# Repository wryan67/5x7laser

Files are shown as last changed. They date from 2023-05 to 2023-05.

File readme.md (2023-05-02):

## 5x7 laser gun

This lasergun can be produced using 5" x 7" sheets of plastic or basswood.  

<a target=_blank href="https://raw.githubusercontent.com/wryan67/5x7laser/main/photos/0171c5aad9a224693b09b8947d892903f43abc70b3.jpg">
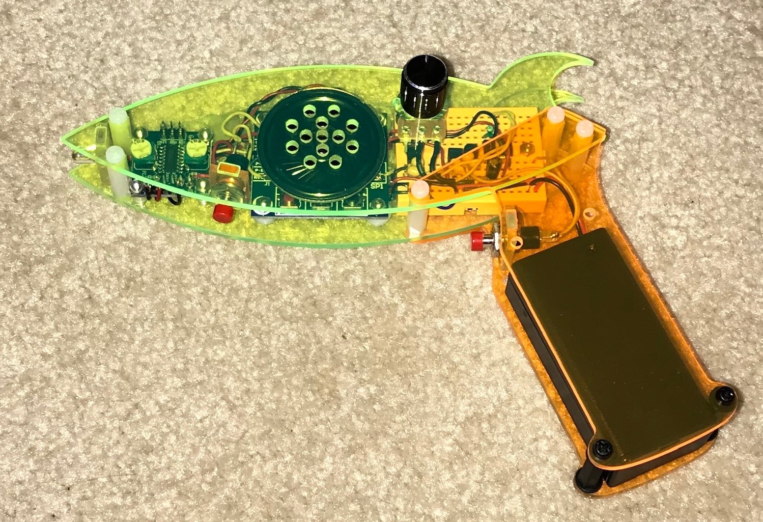
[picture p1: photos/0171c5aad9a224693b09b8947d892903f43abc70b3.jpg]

</a>

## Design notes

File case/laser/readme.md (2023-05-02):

** -----------------------
** For the case and handle, 
** use the System point of 
**      reference!
***  (Use Input CSYS)

If case is solid:
  1. plot-case1.dxf    -   5%  *
  2. plot-case2.dxf    -  35%  *

If case is transparent:
  1. plot-case1m.dxf   -   5%  *
  2. plot-case2m.dxf   -  35%  *

Front only (solid):
  1. plot-case1f.dxf   -   5%  *
  2. plot-case2f.dxf   -  35%  *

If solid handle:
  1. plot-handle1.dxf  -   5%
  2. plot-handle2.dxf  -  35%

If transparent handle:
  1. plot-handle1m.dx  -   5%
  2. plot-handle2m.dx  -  35%

All spacers:
  1.  plot-spacers.dxf  - 35%

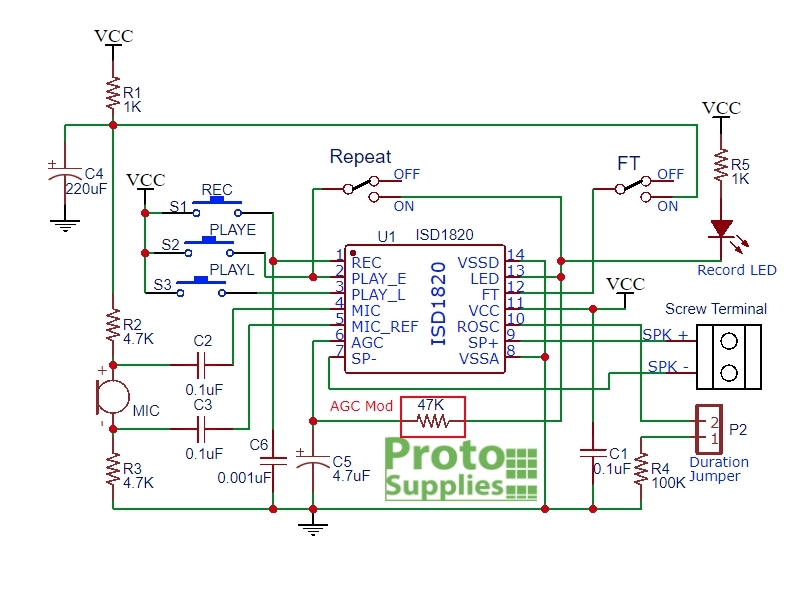
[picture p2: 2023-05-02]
schematic/datasheets/ISD1820-Schematic.jpg

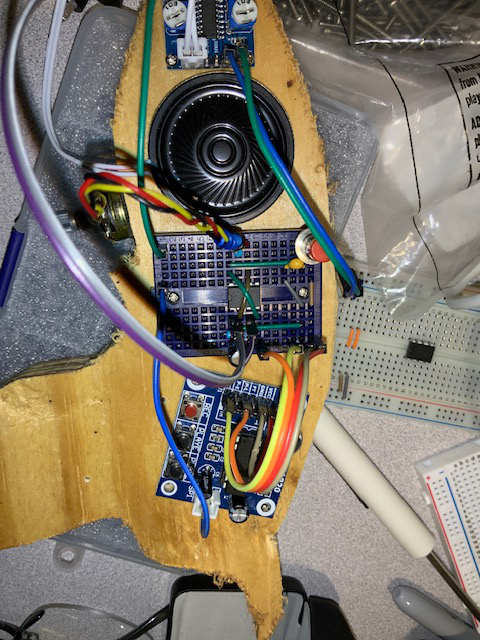
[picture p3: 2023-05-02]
photos/0EB626F5-53C3-48A2-8D61-16B651253186-2090-000001E3B6790D59.JPG

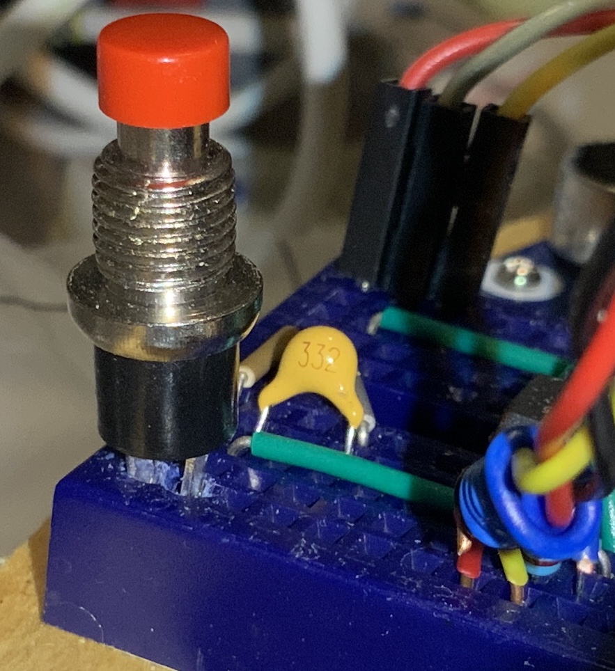
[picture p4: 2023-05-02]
photos/81DD8B38-144E-4452-A4E2-50B8B52A12D1-2090-000001E81675E1E7.jpg

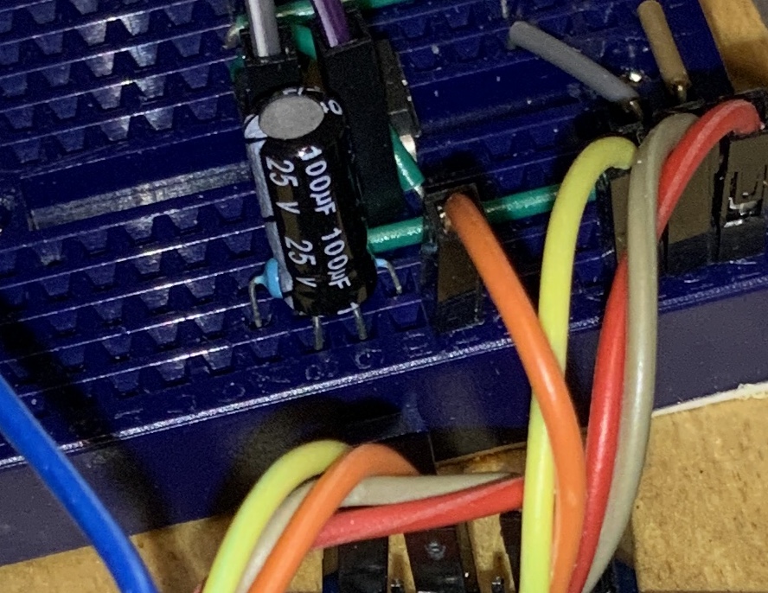
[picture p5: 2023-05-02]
photos/343F5F6C-72F8-4F98-A707-56C6934FBF5B-2090-000001E46D74EF79.jpg

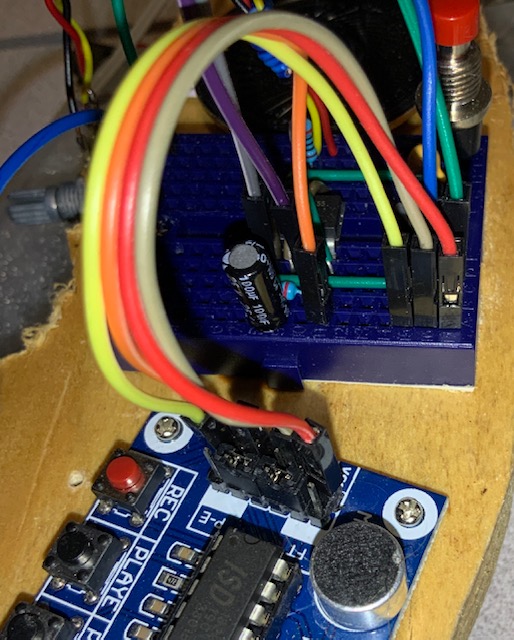
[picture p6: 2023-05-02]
photos/767D7ABD-2B31-472F-8BD6-DF1199BEE2B4-2090-000001E356E05ED7.jpg

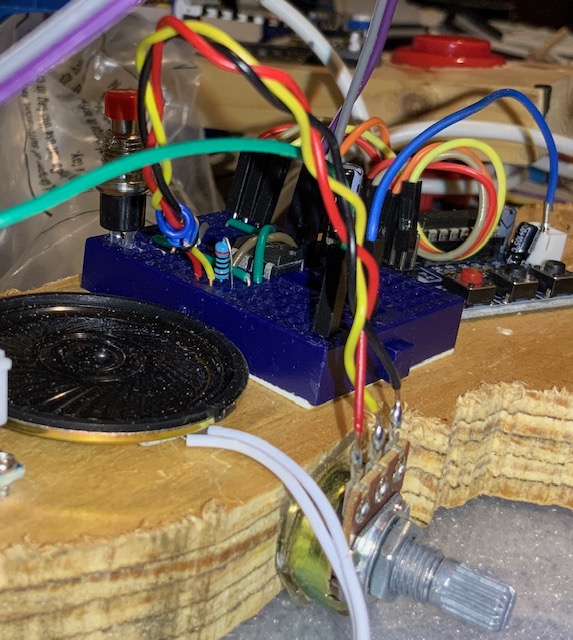
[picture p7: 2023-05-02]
photos/74F2E2E8-B6AC-48FE-9EBC-FF982D334DC6-2090-000001E53F1EEB27.jpg

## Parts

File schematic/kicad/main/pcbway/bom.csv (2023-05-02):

Id | Designator | Footprint | Quantity | Designation | Supplier and ref
1 | REC1 | LED_0805_2012Metric | 1 | Red
2 | J10,J16,J12,J9,J15,J11,J14,J13 | PinHeader_1x02_P2.54mm_Vertical_Wide | 8 | LED
3 | R8,R11 | R_0805_2012Metric | 2 | 10k
4 | C13 | C_0805_2012Metric | 1 | 106
5 | R17,R15,R18,R16 | R_0805_2012Metric | 4 | 200 Ω
6 | J4 | PinHeader_1x02_P2.54mm_Vertical_Wide | 1 | Mic
7 | PWR1,PWR2 | LED_0805_2012Metric | 2 | Green
8 | IC1 | LM4871 | 1 | LM4871MX_NOPB
9 | J1 | PinHeader_1x02_P2.54mm_Vertical_Wide | 1 | Power
10 | C3 | CP_Radial_Tantal_D6.0mm_P2.50mm | 1 | 220 µF
11 | U3 | SOIC-8_3.9x4.9mm_P1.27mm | 1 | NE555D
12 | J2 | PinHeader_1x02_P2.54mm_Vertical_Wide | 1 | Rec
13 | R14,R7,R13 | R_0805_2012Metric | 3 | 100k
14 | J3 | PinHeader_1x02_P2.54mm_Vertical_Wide | 1 | Play
15 | PLAY6,PLAY4,PLAY5,PLAY3 | LED_0805_2012Metric | 4 | Yellow
16 | U2 | ISD1820 | 1 | ISD1820
17 | PLAY1,PLAY2 | LED_0805_2012Metric | 2 | Blue
18 | R12,R19,R9,R4,R1,R6,R10 | R_0805_2012Metric | 7 | 1k
19 | J6 | PinHeader_1x02_P2.54mm_Vertical_Wide | 1 | Speaker
20 | U1 | ua7805-KTT-_R-PSFM-G3_ | 1 | ua7805
21 | J7,J8 | PinHeader_1x02_P2.54mm_Vertical_Wide | 2 | 100k pot
22 | Q3 | SOT-23 | 1 | PMBT2222A
23 | C9,C2,C5,C4 | C_0805_2012Metric | 4 | 104
24 | Q2,Q1 | SOT-23 | 2 | 2PB709AXL
25 | R2,R3 | R_0805_2012Metric | 2 | 4.7k
26 | C1 | C_0805_2012Metric | 1 | 334
27 | C12,C11 | C_0805_2012Metric | 2 | 105
28 | C7,C6,C14 | C_0805_2012Metric | 3 | 102
29 | C8 | C_0805_2012Metric | 1 | 475
30 | C10 | C_0805_2012Metric | 1 | 394
31 | R5 | R_0805_2012Metric | 1 | 80k

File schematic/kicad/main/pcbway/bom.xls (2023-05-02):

Id | Designator | Description/Footprint | Quantity | Value | watt | min voltage | SMD | SMD | THD
1 | R19,R12,R9,R4,R1,R6,R10 | R_0805_2012Metric | 7 | 1k | 1/8w |  | Y | 7 | 0
2 | PLAY2,PLAY1 | LED_0805_2012Metric | 2 | Blue |  |  | Y | 2 | 0
3 | U3 | SOIC-8_3.9x4.9mm_P1.27mm | 1 | NE555D |  |  | Y | 1 | 0
4 | C14,C7,C6 | C_0805_2012Metric | 3 | 102 |  | 10v | Y | 3 | 0
5 | REC1 | LED_0805_2012Metric | 1 | Red |  |  | Y | 1 | 0
6 | J10,J16,J12,J9,J15,J11,J14,J13 | Header_1x02_P2.54mm | 8 | Female_Round_Machine_Pin |  |  | N | 0 | 8
7 | R8,R11 | R_0805_2012Metric | 2 | 10k | 1/8w |  | Y | 2 | 0
8 | C13 | C_0805_2012Metric | 1 | 106 |  | 10v | Y | 1 | 0
9 | R17,R15,R18,R16 | R_0805_2012Metric | 4 | 200 ? | 1/8w |  | Y | 4 | 0
10 | J4 | Header_1x02_P2.54mm | 1 | Female_Round_Machine_Pin |  |  | N | 0 | 1
11 | PWR1,PWR2 | LED_0805_2012Metric | 2 | Green |  |  | Y | 2 | 0
12 | IC1 | SOIC-8_3.9x4.9mm_P1.27mm | 1 | LM4871MX_NOPB |  |  | Y | 1 | 0
13 | J1 | Header_1x02_P2.54mm | 1 | Female_Round_Machine_Pin |  |  | N | 0 | 1
14 | C3 | C_Electrolytic_D6.0mm_P2.50mm_H7mm | 1 | 220 µF |  | ? | N | 0 | 1
15 | J2 | Header_1x02_P2.54mm | 1 | Female_Round_Machine_Pin |  |  | N | 0 | 1
16 | R14,R7,R13 | R_0805_2012Metric | 3 | 100k | 1/8w |  | Y | 3 | 0
17 | J3 | Header_1x02_P2.54mm | 1 | Female_Round_Machine_Pin |  |  | N | 0 | 1
18 | PLAY6,PLAY4,PLAY5,PLAY3 | LED_0805_2012Metric | 4 | Yellow |  |  | Y | 4 | 0
19 | U2 | DIP-14 | 1 | ISD1820 |  |  | N | 0 | 1
20 | J6 | Header_1x02_P2.54mm | 1 | Female_Round_Machine_Pin |  |  | N | 0 | 1
21 | U1 | TO-263 | 1 | UA7805CKTTR |  |  | Y | 1 | 0
22 | J7,J8 | Header_1x02_P2.54mm | 2 | Female_Round_Machine_Pin |  |  | N | 0 | 2
23 | Q3 | SOT-23 | 1 | PMBT2222A |  |  | Y | 1 | 0
24 | C9,C2,C5,C4 | C_0805_2012Metric | 4 | 104 |  | 10v | Y | 4 | 0
25 | Q2,Q1 | SOT-23 | 2 | 2PB709AXL |  |  | Y | 2 | 0
26 | R2,R3 | R_0805_2012Metric | 2 | 4.7k | 1/8w |  | Y | 2 | 0
27 | C1 | C_0805_2012Metric | 1 | 334 |  | 10v | Y | 1 | 0
28 | C12,C11 | C_0805_2012Metric | 2 | 105 |  | 10v | Y | 2 | 0
29 | C8 | C_0805_2012Metric | 1 | 475 |  | 10v | Y | 1 | 0
30 | C10 | C_0805_2012Metric | 1 | 394 |  | 10v | Y | 1 | 0
31 | R5 | R_0805_2012Metric | 1 | 80.6k | 1/8w |  | Y | 1 | 0
 | Totals |  | 64 |  |  |  |  | 47 | 17

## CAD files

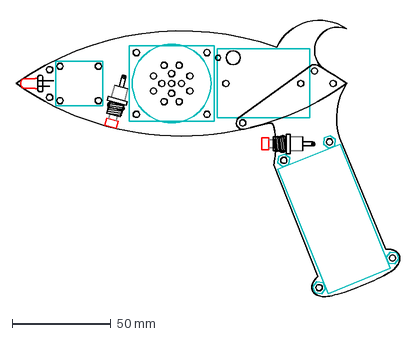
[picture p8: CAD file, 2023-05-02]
case/cnc/lasergun6.dxf
194.8 x 142.3 mm

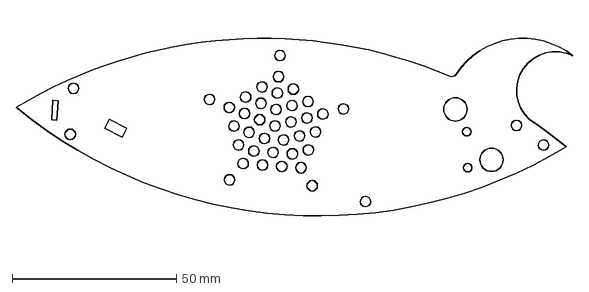
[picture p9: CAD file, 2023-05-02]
case/laser/plot-case2f.dxf
169.3 x 71.6 mm

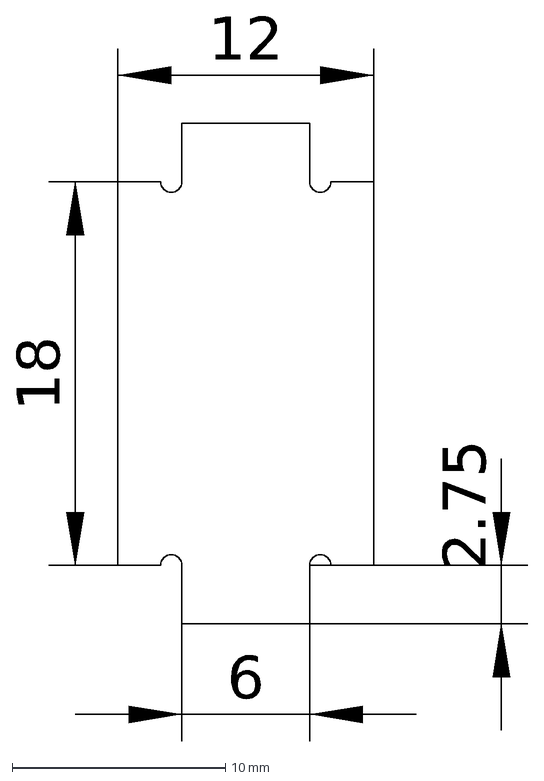
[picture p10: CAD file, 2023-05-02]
case/laser/save/plot-barrel.dxf
12
18
6
2.75

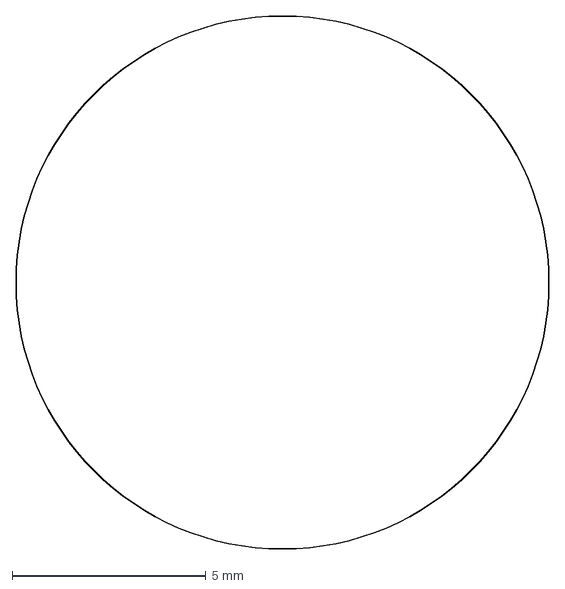
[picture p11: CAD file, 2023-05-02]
knob/knob.dxf
13.8 x 13.8 mm

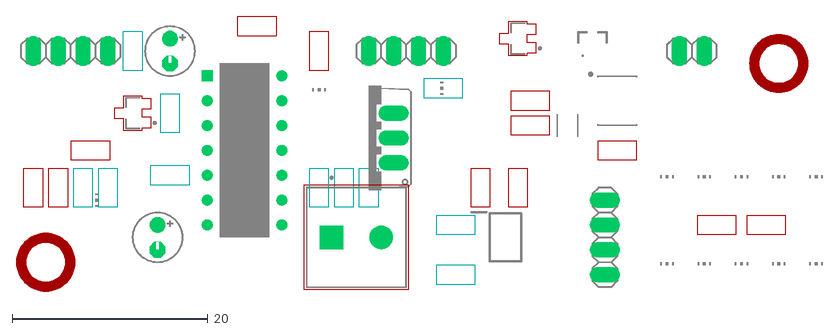
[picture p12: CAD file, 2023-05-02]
schematic/eagle/laser-min.dxf
82.4 x 28.1

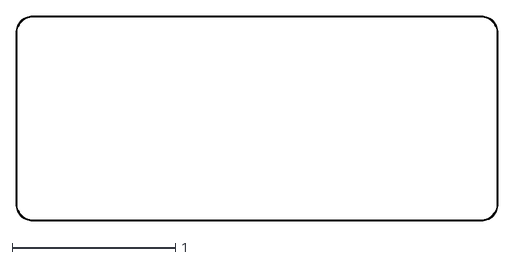
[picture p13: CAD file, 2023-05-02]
schematic/kicad/main/gerber/laser-Edge_Cuts.dxf
2.95 x 1.25

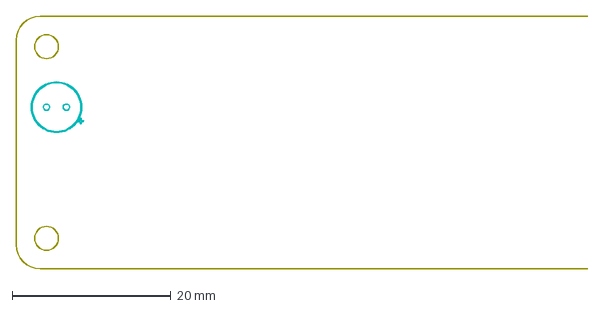
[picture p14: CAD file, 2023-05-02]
schematic/kicad/main/laser-Edge_Cuts.dxf
71.9 x 31.8 mm

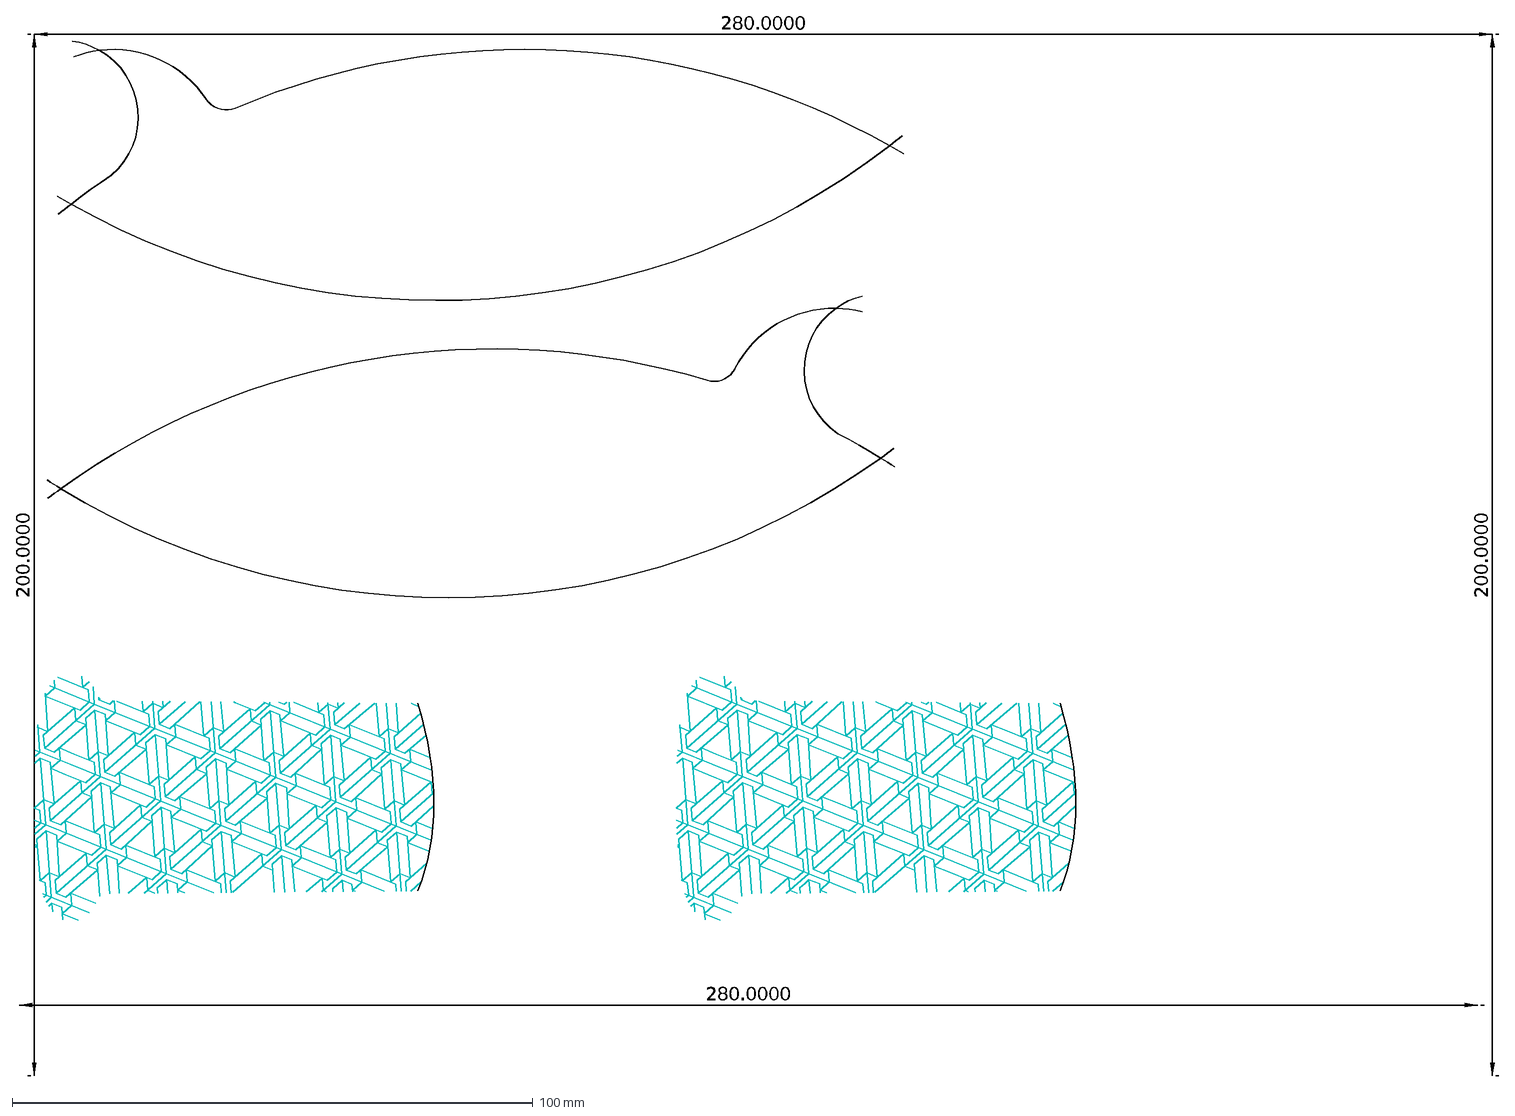
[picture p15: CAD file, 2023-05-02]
case/laser/save/plot1.dxf
200.0000
280.0000

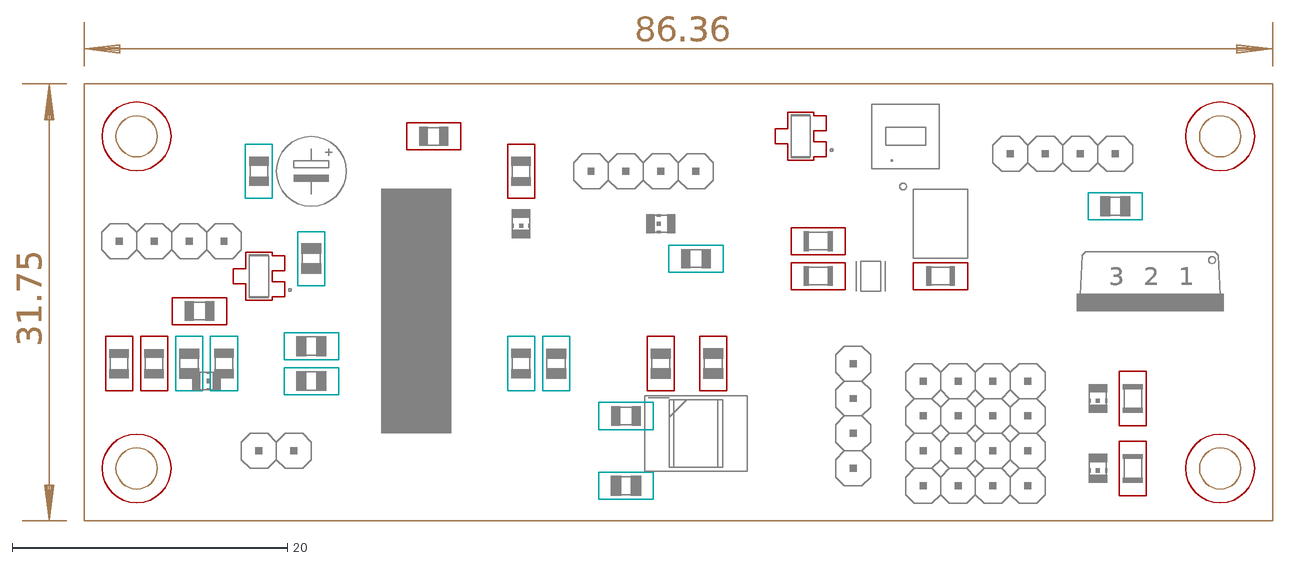
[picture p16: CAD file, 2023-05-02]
schematic/eagle/laser.dxf
31.75
86.36
1
2
3

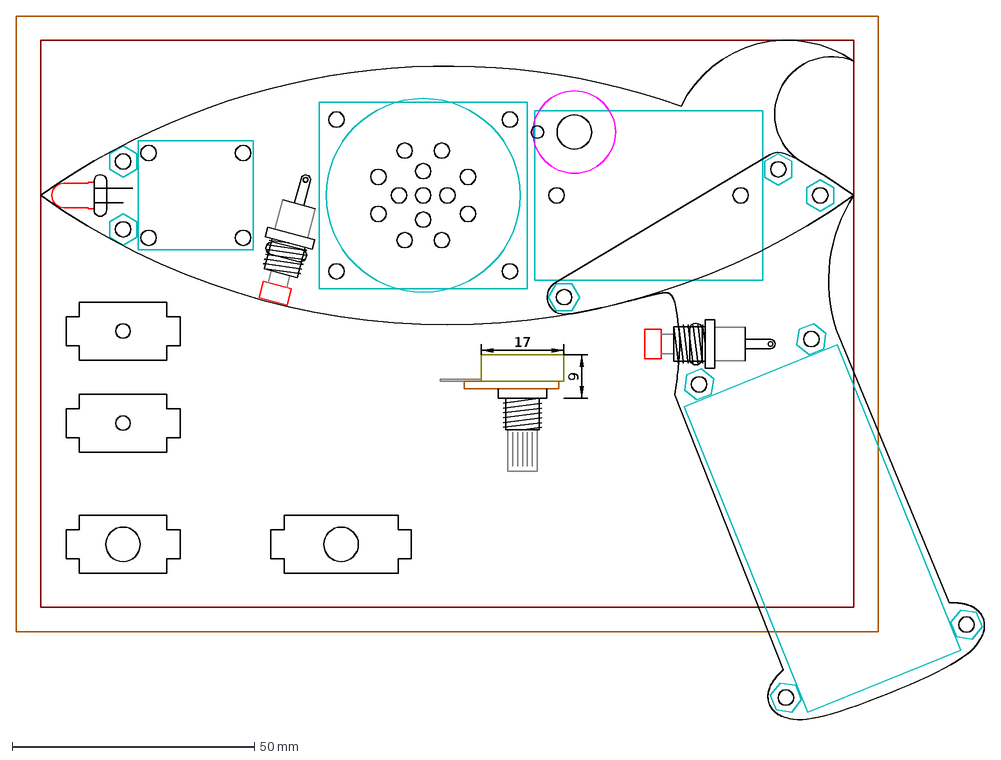
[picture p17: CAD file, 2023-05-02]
case/cnc/lasergun7.dxf
9
17

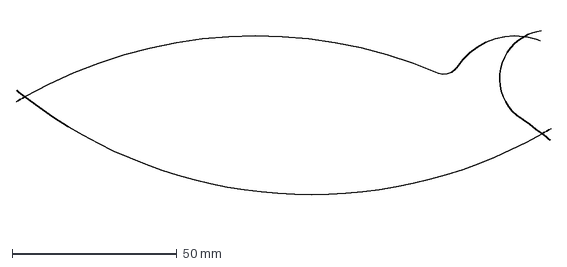
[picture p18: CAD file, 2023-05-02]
case/laser/plot-case1f.dxf
162.6 x 64.0 mm

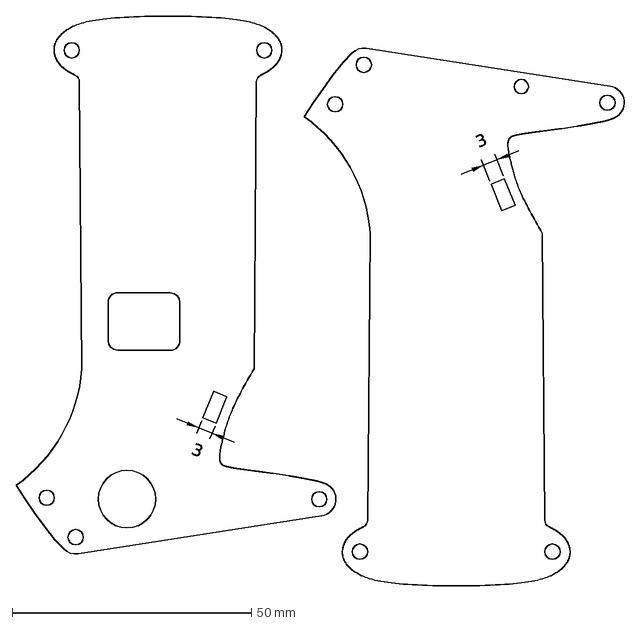
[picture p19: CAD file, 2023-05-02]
case/laser/save/plot-handle2m-bilbo.dxf
3

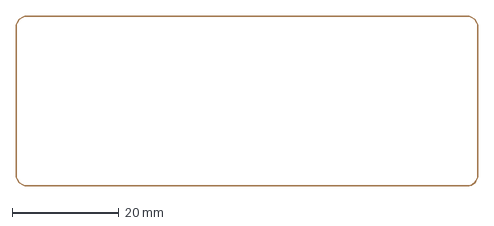
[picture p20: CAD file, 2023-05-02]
schematic/eagle/laser.border.dxf
86.4 x 31.8 mm

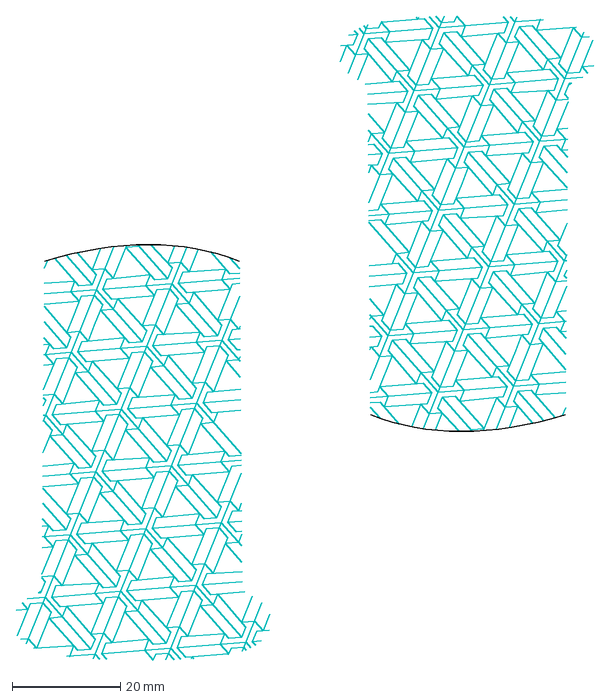
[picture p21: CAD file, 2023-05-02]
case/laser/plot-handle1.dxf
106.6 x 118.9 mm

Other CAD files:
case/laser/lasergun8.dxf
case/cnc/plot-barrel.dxf
case/laser/save/plot-handle.dxf
archive/lasergun.dxf
archive/lasergun2.dxf
archive/lasergun3.dxf
archive/lasergun4.dxf
archive/lasergun5.dxf
archive/plot-body.dxf
archive/plot-handle.dxf
archive/plot-spacers.dxf
archive/plot1.dxf
archive/slot.dxf
archive/test-handle.dxf
archive/test-handle2.dxf
case/cnc/20mm spacer.dxf
case/cnc/lasergun8.dxf
case/cnc/plot-handle-back.dxf
case/cnc/plot-handle.dxf
case/cnc/plot-spacers.dxf
case/cnc/spacers.dxf
case/laser/lasergun10.dxf
case/laser/lasergun11.dxf
case/laser/plot-case1.dxf
case/laser/plot-case1m.dxf
case/laser/plot-case2.dxf
case/laser/plot-case2m.dxf
case/laser/plot-handle.dxf
case/laser/plot-handle1m.dxf
case/laser/plot-handle2.dxf
case/laser/plot-handle2m.dxf
case/laser/plot-spacers.dxf
case/laser/save/20mm spacer.dxf
case/laser/save/controller-pcb.dxf
case/laser/save/plot-case1.dxf
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

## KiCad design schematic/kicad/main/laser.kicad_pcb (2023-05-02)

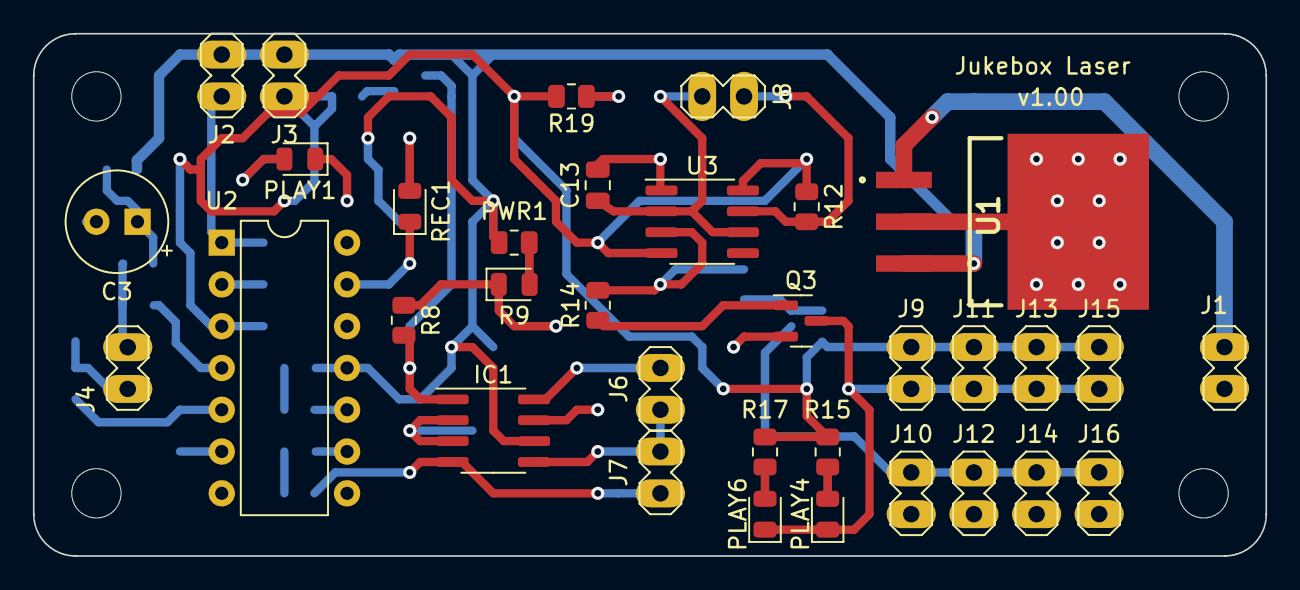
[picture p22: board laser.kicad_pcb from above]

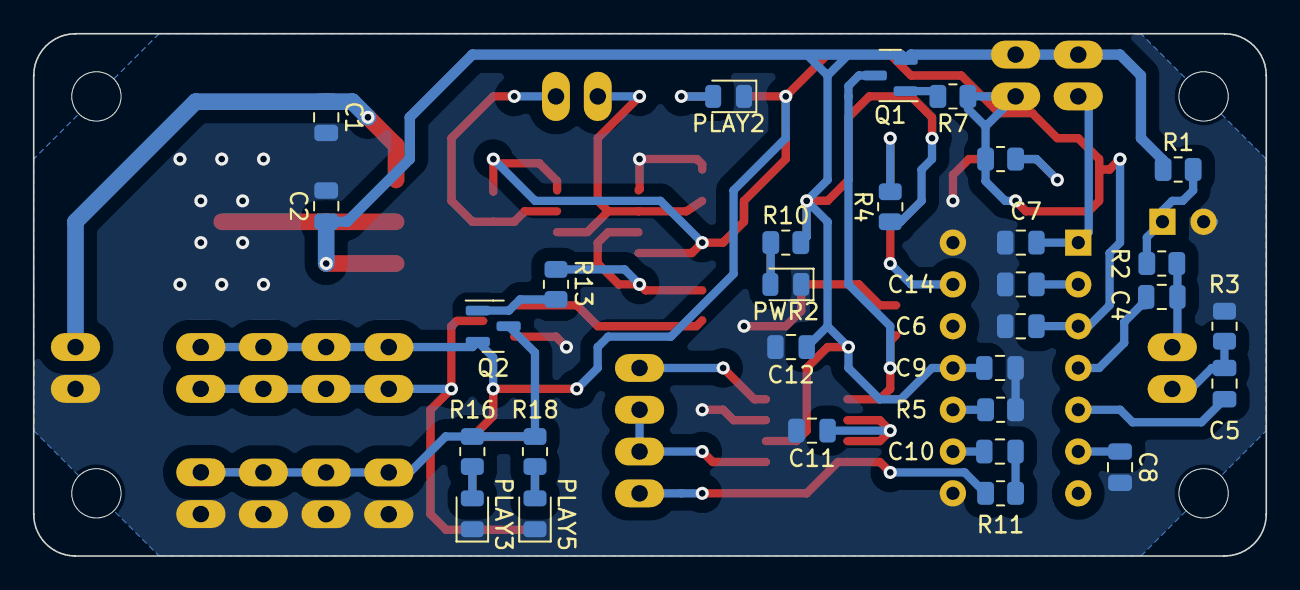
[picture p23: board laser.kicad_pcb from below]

Board: 2 copper layers, 74.9 x 31.8 mm, 64 parts (30 on the bottom side), 38 nets.

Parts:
C1: 334; C_0805_2012Metric
C2, C4, C5, C9: 104; C_0805_2012Metric
C3: 220 µF; CP_Radial_Tantal_D6.0mm_P2.50mm
C6, C7, C14: 102; C_0805_2012Metric
C8: 475; C_0805_2012Metric
C10: 394; C_0805_2012Metric
C11, C12: 105; C_0805_2012Metric
C13: 106; C_0805_2012Metric
IC1: LM4871MX_NOPB; LM4871
J1: Power; PinHeader_1x02_P2.54mm_Vertical_Wide
J2: Rec; PinHeader_1x02_P2.54mm_Vertical_Wide
J3: Play; PinHeader_1x02_P2.54mm_Vertical_Wide
J4: Mic; PinHeader_1x02_P2.54mm_Vertical_Wide
J6: Speaker; PinHeader_1x02_P2.54mm_Vertical_Wide
J7, J8: 100k pot; PinHeader_1x02_P2.54mm_Vertical_Wide
J9, J10, J11, J12, J13, J14, J15, J16: LED; PinHeader_1x02_P2.54mm_Vertical_Wide
PLAY1, PLAY2: Blue; LED_0805_2012Metric
PLAY3, PLAY4, PLAY5, PLAY6: Yellow; LED_0805_2012Metric
PWR1, PWR2: Green; LED_0805_2012Metric
Q1, Q2: 2PB709AXL; SOT-23
Q3: PMBT2222A; SOT-23
R1, R4, R6, R9, R10, R12, R19: 1k; R_0805_2012Metric
R2, R3: 4.7k; R_0805_2012Metric
R5: 80k; R_0805_2012Metric
R7, R13, R14: 100k; R_0805_2012Metric
R8, R11: 10k; R_0805_2012Metric
R15, R16, R17, R18: 200 Ω; R_0805_2012Metric
REC1: Red; LED_0805_2012Metric
U1: ua7805; ua7805-KTT-_R-PSFM-G3_
U2: ISD1820
U3: NE555D; SOIC-8_3.9x4.9mm_P1.27mm

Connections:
+5v: C2.1, C9.1, C12.1, IC1.6 (VDD), J2.2, J3.2, Q1.2 (E), R1.1, R4.1, R9.2, R10.2, U1.3 (OUTPUT), U2.11 (Vcc)
+9v: C1.1, J1.2, U1.1 (INPUT)
/Amplifier/SPK+: IC1.5 (VO1), J6.2, J7.1
/Amplifier/SPK-: IC1.8 (VO2), J6.1
/Jukebox/AGC: C8.1, U2.6 (AGC)
/Jukebox/M+: C4.1, U2.4 (MIC(+))
/Jukebox/M-: C5.1, U2.5 (MIC(-))
/Jukebox/PLAY_E: C14.1, U2.2 (PLAY_E)
Flasher Speed: J8.1, R12.2, U3.7 (DIS)
GND: C1.2, C2.2, C3.2, C6.2, C7.2, C8.2, C9.2, C11.2, C12.2, C13.2, C14.2, IC1.7 (GND), J1.1, J10.2, J12.2, J14.2, J16.2, PLAY1.1 (K), PLAY2.1 (K), PLAY3.1 (K), PLAY5.1 (K), PWR1.1 (K), PWR2.1 (K), Q3.2 (E), R3.2, R5.2, R8.1, U1.2 (COMMON_1), U1.4 (COMMON_2), U2.8 (VSSA), U2.14 (VSSD), U3.1 (GND)
Mic(+): C4.2, J4.2, R2.2
Mic(-): C5.2, J4.1, R3.1
unnamed: C3.1, R1.2, R2.1
unnamed: C10.2, R11.2
unnamed: C11.1, IC1.2 (BYPASS), IC1.3 (+IN)
unnamed: C13.1, J8.2, U3.2 (TR), U3.6 (THR)
unnamed: J10.1, J12.1, J14.1, J16.1, Q2.3 (C), R16.2, R18.2
unnamed: J9.2, J11.2, J13.2, J15.2, PLAY4.1 (K), PLAY6.1 (K), Q3.3 (C)
unnamed: PLAY1.2 (A), R6.1
unnamed: PLAY2.2 (A), R19.1
unnamed: PLAY3.2 (A), R16.1
unnamed: PLAY4.2 (A), R15.1
unnamed: PLAY5.2 (A), R18.1
unnamed: PLAY6.2 (A), R17.1
unnamed: PWR1.2 (A), R9.1
unnamed: PWR2.2 (A), R10.1
unnamed: Q1.1 (B), R7.2
unnamed: Q2.1 (B), R13.2
unnamed: Q3.1 (B), R14.1
unnamed: R4.2, REC1.2 (A)
unnamed: REC1.1 (K), U2.13 (RECLED)
unnamed: R5.1, U2.10 (ROSC)
unnamed: R13.1, R14.2, U3.3 (Q)
PLAY: C6.1, J3.1, J9.1, J11.1, J13.1, J15.1, Q2.2 (E), R6.2, R7.1, R12.1, R15.2, R17.2, R19.2, U2.3 (PLAY_L), U3.4 (R), U3.8 (VCC)
REC: C7.1, J2.1, U2.1 (REC)
SPK(+): C10.1, U2.9 (SPK(+))
Shutdown: IC1.1 (SHUTDOWN), Q1.3 (C), R8.2
VOL(-): IC1.4 (-IN), J7.2, R11.1

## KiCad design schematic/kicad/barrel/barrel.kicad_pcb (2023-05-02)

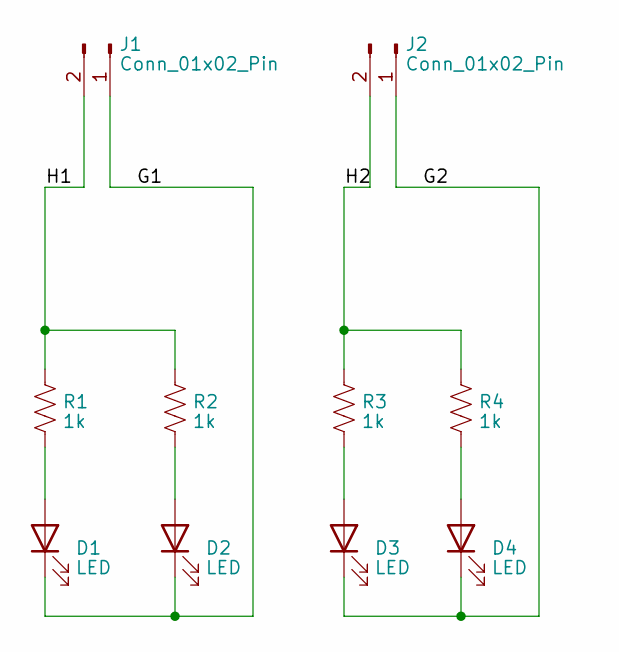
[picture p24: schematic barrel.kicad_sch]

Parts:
D1, D2, D3, D4: LED; LED_0805_2012Metric
J1, J2: Conn_01x02_Pin; PinHeader_1x02_P2.54mm_Vertical_Wide
R1, R2, R3, R4: 1k; R_0805_2012Metric

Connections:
/G1: D1.1 (K), D2.1 (K), J1.1
/G2: D3.1 (K), D4.1 (K), J2.1
/H1: J1.2, R1.1, R2.1
/H2: J2.2, R3.1, R4.1
unnamed: D1.2 (A), R1.2
unnamed: D2.2 (A), R2.2
unnamed: D3.2 (A), R3.2
unnamed: D4.2 (A), R4.2

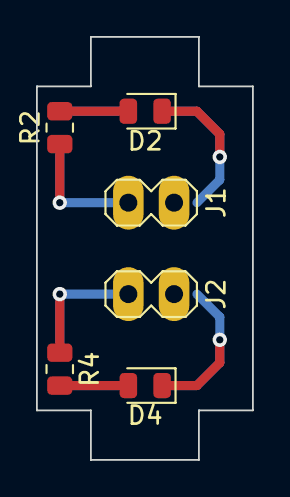
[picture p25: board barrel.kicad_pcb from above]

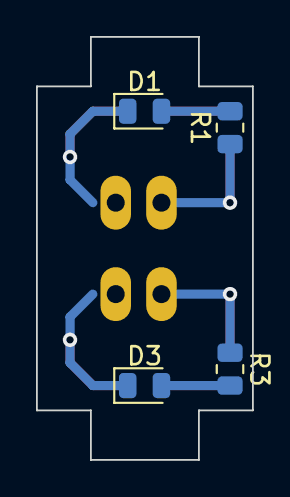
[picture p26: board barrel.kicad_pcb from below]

Board: 2 copper layers, 12.0 x 23.5 mm, 10 parts (4 on the bottom side), 8 nets.

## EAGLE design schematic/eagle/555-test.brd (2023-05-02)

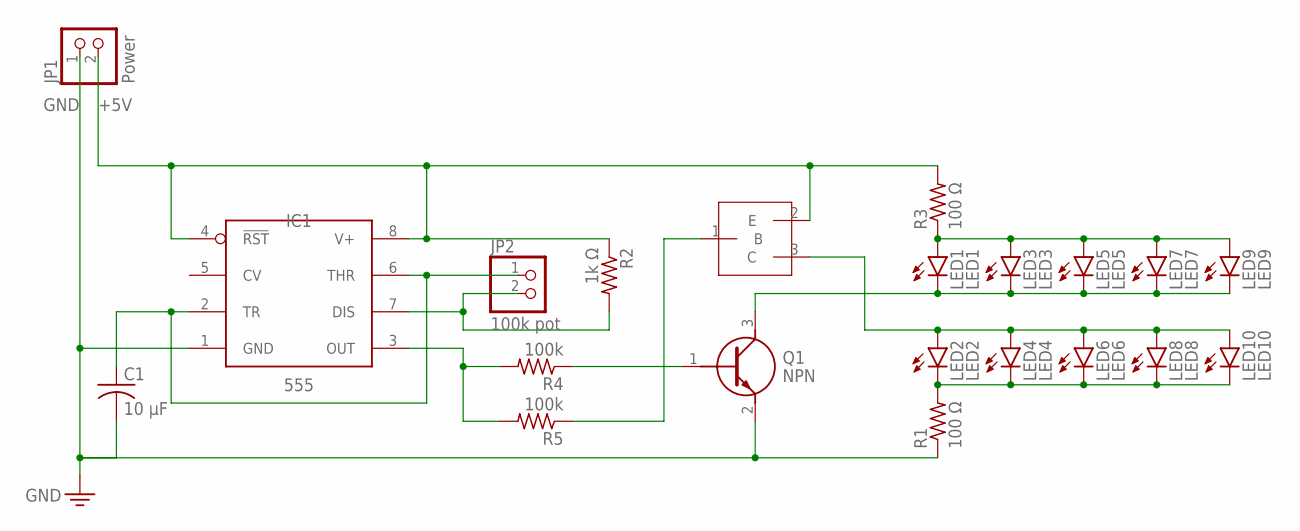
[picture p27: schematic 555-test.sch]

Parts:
C1: 10 μF; CAPC2012X110
IC1: 555; SOIC127P599X175-8N
JP1: Power; 1X02
JP2: 100k pot; 1X02
LED1: LED1; CHIP-LED0805
LED2: LED2; CHIP-LED0805
LED3: LED3; CHIP-LED0805
LED4: LED4; CHIP-LED0805
LED5: LED5; CHIP-LED0805
LED6: LED6; CHIP-LED0805
LED7: LED7; CHIP-LED0805
LED8: LED8; CHIP-LED0805
LED9: LED9; CHIP-LED0805
LED10: LED10; CHIP-LED0805
Q1: NPN; PMBT2222A215
R1, R3: 100 Ω; M0805
R2: 1k Ω; M0805
R4, R5: 100k; M0805
U$1: PNP; SOT95P230X110-3N

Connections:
+5V: IC1.4 (!RST), IC1.8 (V+), JP1.2, R2.1, R3.2, U$1.2 (E)
GND: C1.2, IC1.1 (GND), JP1.1, Q1.2 (E), R1.1
unnamed: C1.1, IC1.2 (TR), IC1.6 (THR), JP2.1
unnamed: IC1.3 (OUT), R4.2, R5.2
unnamed: Q1.1 (B), R4.1
unnamed: LED2.C, LED4.C, LED6.C, LED8.C, LED10.C, R1.2
unnamed: IC1.7 (DIS), JP2.2, R2.2
unnamed: LED1.A, LED3.A, LED5.A, LED7.A, LED9.A, R3.1
unnamed: LED1.C, LED3.C, LED5.C, LED7.C, LED9.C, Q1.3 (C)
unnamed: R5.1, U$1.1 (B)
unnamed: LED2.A, LED4.A, LED6.A, LED8.A, LED10.A, U$1.3 (C)

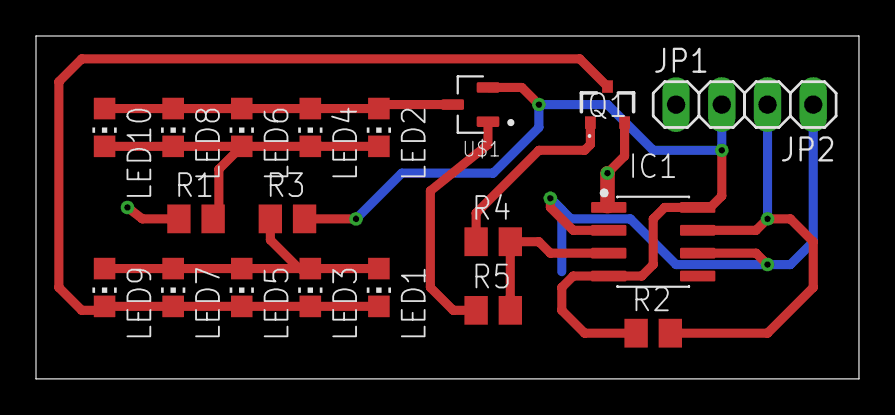
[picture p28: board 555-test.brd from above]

Board: 2 copper layers, 45.7 x 19.1 mm, 21 parts (1 on the bottom side), 11 nets.

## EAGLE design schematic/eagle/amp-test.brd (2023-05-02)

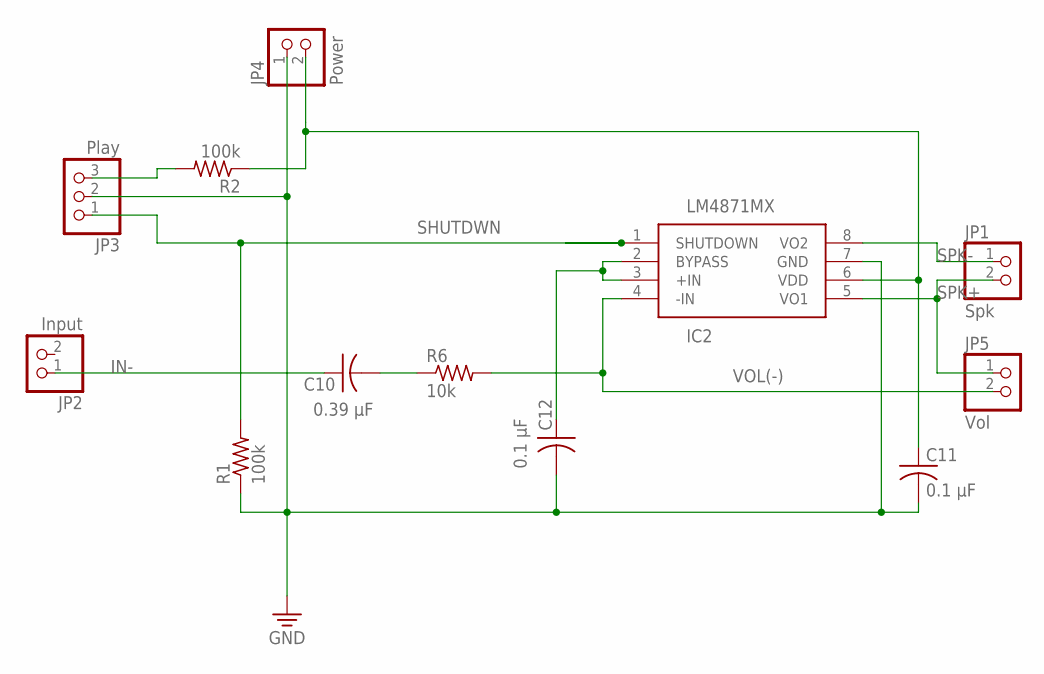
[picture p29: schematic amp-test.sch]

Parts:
C10: 0.39 μF; C0805
C11, C12: 0.1 μF; C0805
IC2: LM4871MX; SOIC127P600X175-8N
JP1: Spk; 1X02
JP2: Input; 1X02
JP3: Play; 1X03
JP4: Power; 1X02
JP5: Vol; 1X02
R1, R2: 100k; R0805
R6: 10k; R0805

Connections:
+5V: C11.1, IC2.6 (VDD), JP4.2, R2.1
GND: C11.2, C12.2, IC2.7 (GND), JP3.2, JP4.1, R1.1
IN-: C10.1, JP2.1
unnamed: JP3.3, R2.2
unnamed: C10.2, R6.1
unnamed: C12.1, IC2.2 (BYPASS), IC2.3 (+IN)
SHUTDWN: IC2.1 (SHUTDOWN), JP3.1, R1.2
SPK+: IC2.5 (VO1), JP1.2, JP5.1
SPK-: IC2.8 (VO2), JP1.1
VOL(-): IC2.4 (-IN), JP5.2, R6.2

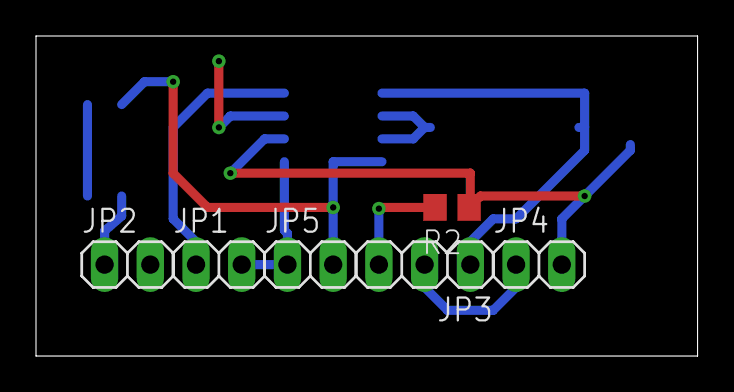
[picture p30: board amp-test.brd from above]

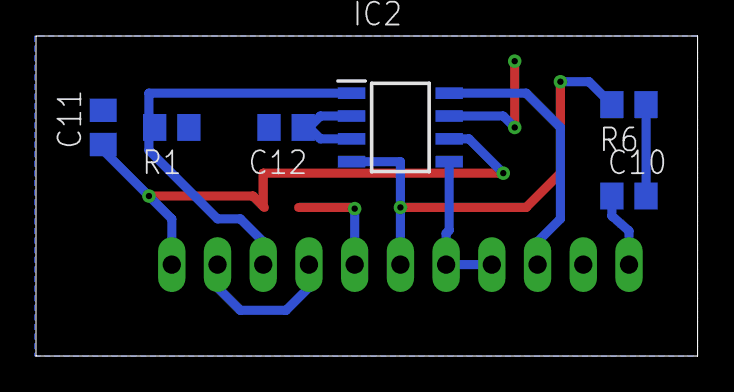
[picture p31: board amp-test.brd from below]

Board: 2 copper layers, 36.8 x 17.8 mm, 12 parts (6 on the bottom side), 10 nets.

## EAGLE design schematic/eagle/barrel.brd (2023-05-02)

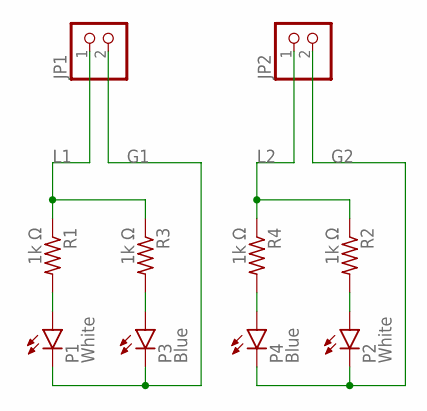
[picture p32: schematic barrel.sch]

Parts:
JP1, JP2: PINHD-1X2; 1X02
P1, P2: White; CHIP-LED0805
P3, P4: Blue; CHIP-LED0805
R1, R2, R3, R4: 1k Ω; M0805

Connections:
G1: JP1.2, P1.C, P3.C
G2: JP2.2, P2.C, P4.C
L1: JP1.1, R1.1, R3.1
L2: JP2.1, R2.1, R4.1
unnamed: P1.A, R1.2
unnamed: P3.A, R3.2
unnamed: P2.A, R2.2
unnamed: P4.A, R4.2

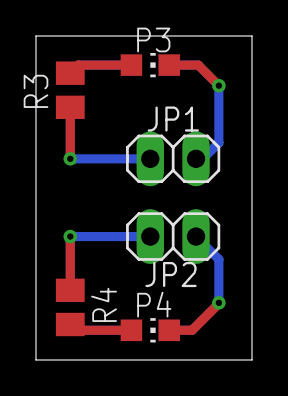
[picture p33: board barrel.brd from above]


Board: 2 copper layers, 12.0 x 18.0 mm, 10 parts (4 on the bottom side), 8 nets.

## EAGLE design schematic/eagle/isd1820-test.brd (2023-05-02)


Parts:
C1, C2, C3, C4: 0.1 μF; C0805
C5, C6, C7: 0.001 μF; C0805
C9: 0.33 μF; C0805
C10: 4.7 μF; E2,5-5
C11: 220 μF; E2,5-5
IC1: 7805TV; TO220V
J1: POWER; CUI_TB004-508-02BE
JP1, JP5: PWR; 1X02
JP2: MIC; 1X02
JP3: REC; 1X02
JP4: PLAY; 1X02
JP6: SHUTDWN; 1X02
JP7: SPK; 1X02
PLAY: Blue; CHIP-LED0805
PWR: Red; CHIP-LED0805
R1, R5, R6, R9: 1k; R0805
R2, R3: 4.7k; R0805
R4: 80k; R0805
R7: 10k; R0805
R8: 100k; R0805
REC: Red; CHIP-LED0805
U$1: ISD1820PY
U$2: PNP; SOT95P230X110-3N

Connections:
+5V: C1.1, C4.1, IC1.3 (VO), JP1.2, JP3.2, JP4.2, JP5.1, R1.2, R5.2, R9.2, U$1.VCC, U$2.2 (E)
<PLAY>: JP6.2, R7.2, U$2.3 (C)
AGC: C10.+, U$1.AGC
GND: C1.2, C4.2, C5.2, C6.2, C7.2, C9.2, C10.-, C11.-, IC1.2 (GND), J1.1, JP1.1, JP5.2, PLAY.C, PWR.C, R3.2, R4.2, R7.1, U$1.VSSA, U$1.VSSD
M+: C2.1, U$1.MIC(+)
M-: C3.1, U$1.MIC(-)
MIC(+): C2.2, JP2.2, R2.2
MIC(-): C3.2, JP2.1, R3.1
unnamed: PLAY.A, R6.1
unnamed: PWR.A, R9.1
unnamed: R8.2, U$2.1 (B)
unnamed: R4.1, U$1.ROSC
unnamed: C9.1, IC1.1 (VI), J1.2
unnamed: C11.+, R1.1, R2.1
unnamed: R5.1, REC.A
unnamed: REC.C, U$1.LED
PLAY: C6.1, JP4.1, JP6.1, R6.2, R8.1, U$1.PLAY_L
PLAY_E: C7.1, U$1.PLAY_E
REC: C5.1, JP3.1, U$1.REC
SPK(+): JP7.1, U$1.SPK(+)
SPK(-): JP7.2, U$1.SPK(-)



Board: 2 copper layers, 49.6 x 29.2 mm, 33 parts (12 on the bottom side), 21 nets.

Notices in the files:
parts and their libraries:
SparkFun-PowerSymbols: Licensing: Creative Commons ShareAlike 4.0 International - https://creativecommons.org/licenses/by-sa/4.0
